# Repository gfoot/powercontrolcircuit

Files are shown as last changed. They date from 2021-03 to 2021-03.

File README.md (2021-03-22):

# Soft Power Switch Circuit with Tunable Overcurrent Protection Cutoff

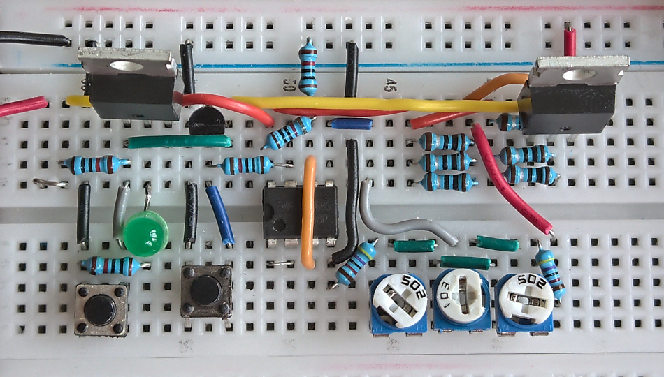
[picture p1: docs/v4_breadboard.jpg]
Power control circuit assembled on breadboard
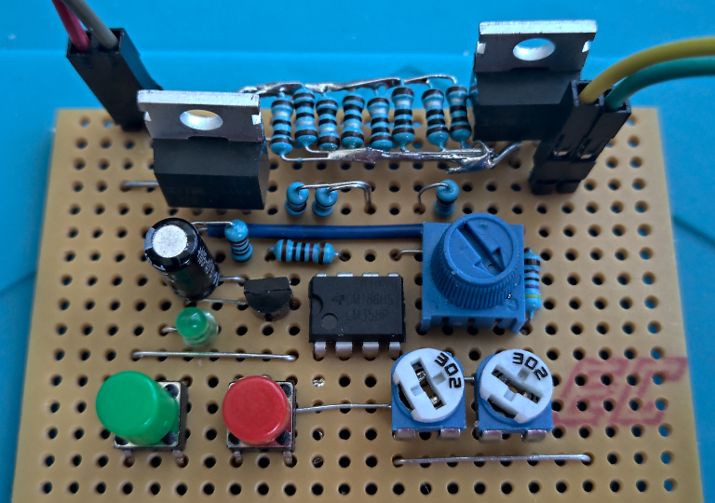
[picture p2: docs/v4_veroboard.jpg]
Power control circuit assembled on veroboard
 |  | <a href="http://www.youtube.com/watch?feature=player_embedded&v=DyxhS2SbpGM" target="_blank">Demo video on YouTube</a>
:----:|:----:|:----:
Assembled on breadboard | Assembled on veroboard | Demo video

This is a circuit for soft-switching a 5V DC input, with a configurable current limit cutoff, tested from around 10mA up to 1.2A.

This is useful because it protects your power supply, wiring, and components against adverse effects due to things like 
short circuiting, accidental reversed power polarity, placing components incorrectly or backwards in a circuit, or other
component failure.

It's not a boost/buck converter or regulator, just a switch for an existing regulated DC input.

## Operation

Press SW1 to turn the power on.  The LED indicates that power is on.  Press SW2 to turn the power off.

Use RV2 and RV3 to tune the range of currents that are selectable.  See [configuration guide](docs/configuration.md) for the tuning procedure.

Once tuned, RV1 selects the current limit.  When more than this amount of current is drawn, the circuit automatically powers off.

## Schematic

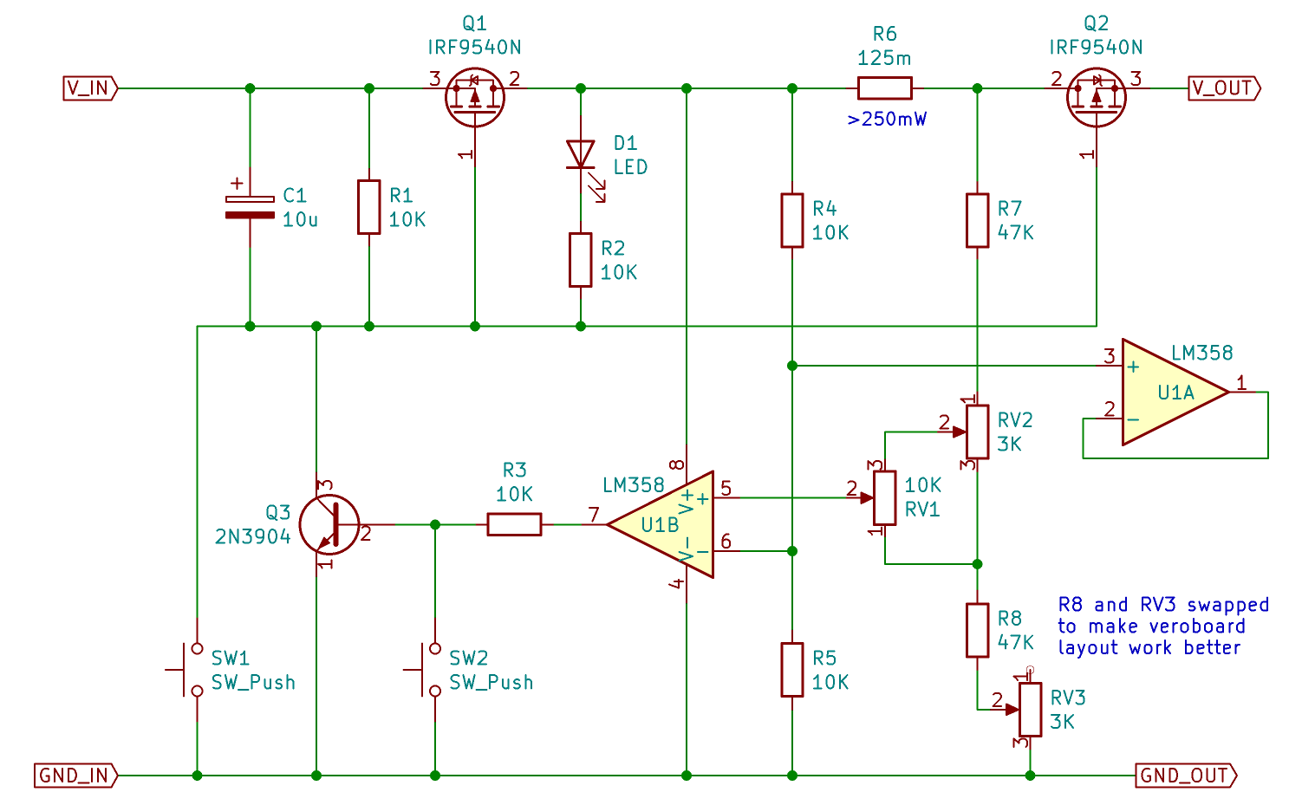
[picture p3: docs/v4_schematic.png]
Power control circuit schematic (v4)


## Bill of Materials

| Ref | Qty  | Spec | Notes |
| --- |:----:| ---- | ----- |
| Q1-2 | 2  | IRF9540N | P-channel power MOSFET - ideally low RDS(on) at VGS=-4.25V |
| Q3 | 1  | 2N3904 | NPN BJT transistor |
| R1-5 | 5  | 10K | Resistor |
| R6 | 1  | ~0.1 ohm | Power resistor, 1A continuous current, at least 1W recommended |
| R7-8 | 2  | 47K | Resistor |
| RV1-2  | 2  | 3K | Trim pots |
| RV3 | 1  | 10K | Potentiometer |
| U1 | 1  | LM385 | Operational amplifier |
| C1 | 1  | 10u | Capacitor to prevent accidental power-on (may not be necessary) |

Exact component choices are not critical.  With the above components, and 6x1ohm 250mW resistors in parallel for R6, at a continuous 1A load, 
the resistors get slightly warm to the touch and the MOSFET tabs measure 60C-70C, in open air with no heatsinks or active cooling.

The added output impedance appears to be approximately 0.75 ohms with these components, at a load current of 1A; lower currents 
lead to lower impedance.  Choosing Q1-2 with lower RDS(on) at -4.25V or more will have the greatest effect on impedance.

## Improvements

I'm considering the following:

* Use a charge pump to lower the gate voltage to Q1-2, to improve impedance at high loads
* Configure the op amp with feedback to amplify the voltage difference, in case it makes tuning the cutoff simpler
* Add an optional linear regulator to guarantee output voltage at high loads

Other suggestions very welcome!

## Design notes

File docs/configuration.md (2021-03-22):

# Configuring the current limiting feature

The circuit includes a series of resistors and potentiometers that form a
potential divider to determine the cutoff current.

Generally the range this needs to cover is approximately a division ratio
between about 50% and 55%.  Three potentiometers are used to configure this -
the idea is that RV2 and RV3 are "trim pots", used to fairly permanently set
some endpoints for the range that is then dynamically configured by the user
using RV1.

This document describes a method for calibrating these endpoints by tuning the
settings of RV2 and RV3.

To do this for large currents you really need a decent quality adjustable
electronic load, that can draw the required current for at least around 20s
without overheating - and preferably indefinitely.  I built a basic one from a
MOSFET and a bank of resistors which works well but requires a heatsink for
long term operation.  I'll discuss lower-tech alternatives below after going
through the general procedure.

# Tuning procedure

Before starting, you need a range of current limits in mind.

I've generally used 10mA and 1A as the target thresholds.  If you don't need
high currents, you may choose to reduce the upper limit to get more control at
the low end.

## Step 1 - Initial setup

* Set RV2 to a medium setting and RV3 to its maximum setting.
* Set RV1 to its minimum setting.
* Set your variable load to draw the low current amount, e.g. 10mA.
* Turn on the power; it should stay on.  If it doesn't, then increase RV2 until
it does stay on.

If it's not possible to get the power to stay on then you may need to adjust
some component values - using wider ranged pots for RV2 and RV3, or increasing
R7 and R8.

## Step 2 - Tune minimum current setting via RV3

* Set your variable load to draw the low current
* Set RV1 to minimum
* Turn on the circuit and check it stays on - if it doesn't, increase RV3 until it stays on
* Then decrease RV3 until it turns off

## Step 3 - Tune maximum current setting via RV2

* Set your variable load to draw the high current amount
* Set RV1 to maximum
* Turn on the circuit and check it stays on - if it doesn't, increase RV2 until it stays on
* Decrease RV2 until the circuit turns off

Repeat steps 2 and 3 until you're happy with the behaviour at the extreme
settings of RV1.  For me it only takes a couple of iterations to get settings
that work well.

You should then find that the rest of RV1's range maps fairly linearly to the
current values in-between.

# If you don't have a variable electronic load...

In case you don't have a proper electronic load that can draw a configurable
constant current, here are some other options.

For the low current calibration, you can just use normal resistors.  10mA over
5V requires 500 ohms and generates 50mW, which is fine for typical cheap
resistors - it'll get warm but not hot.  You can check the actual current flow
using an ammeter of course, and if you're concerned about the heat at 50mW, you
could use two 1K resistors in parallel instead.

For the high current calibration, normal resistors aren't really practical as
they can't deal with the amount of heat that gets generated - it's 5W for 1A
over 5V.  You'd need to spread that over about 100 resistors.  If you have a
suitable power resistor, with heat sink, then you could use that.

Personally I made my own electronic load to help test this circuit, which
worked quite well.  I think I'm currently using 9 x 47-ohm resistors in
parallel and an IRFZ34 MOSFET with heat sink, and a potentiometer to control
the gate voltage.  There are sure to be better designs available online.

It doesn't matter what the load is though so long as it draws this current, so
if you have any device that draws 1A at 5V, you could hook that up.  It doesn't
need to be a variable load.

You can also instead tune the "medium" setting of RV1 to match a lower current
limit - perhaps making it match the current draw of one of your own circuits.
Then turning RV1 up to maximum would allow for approximately doubling that
current flow before cutting off.

Finally, if you're not using a regulated load, check the actual current flow
using an ammeter in series, as unregulated loads will vary with temperature.

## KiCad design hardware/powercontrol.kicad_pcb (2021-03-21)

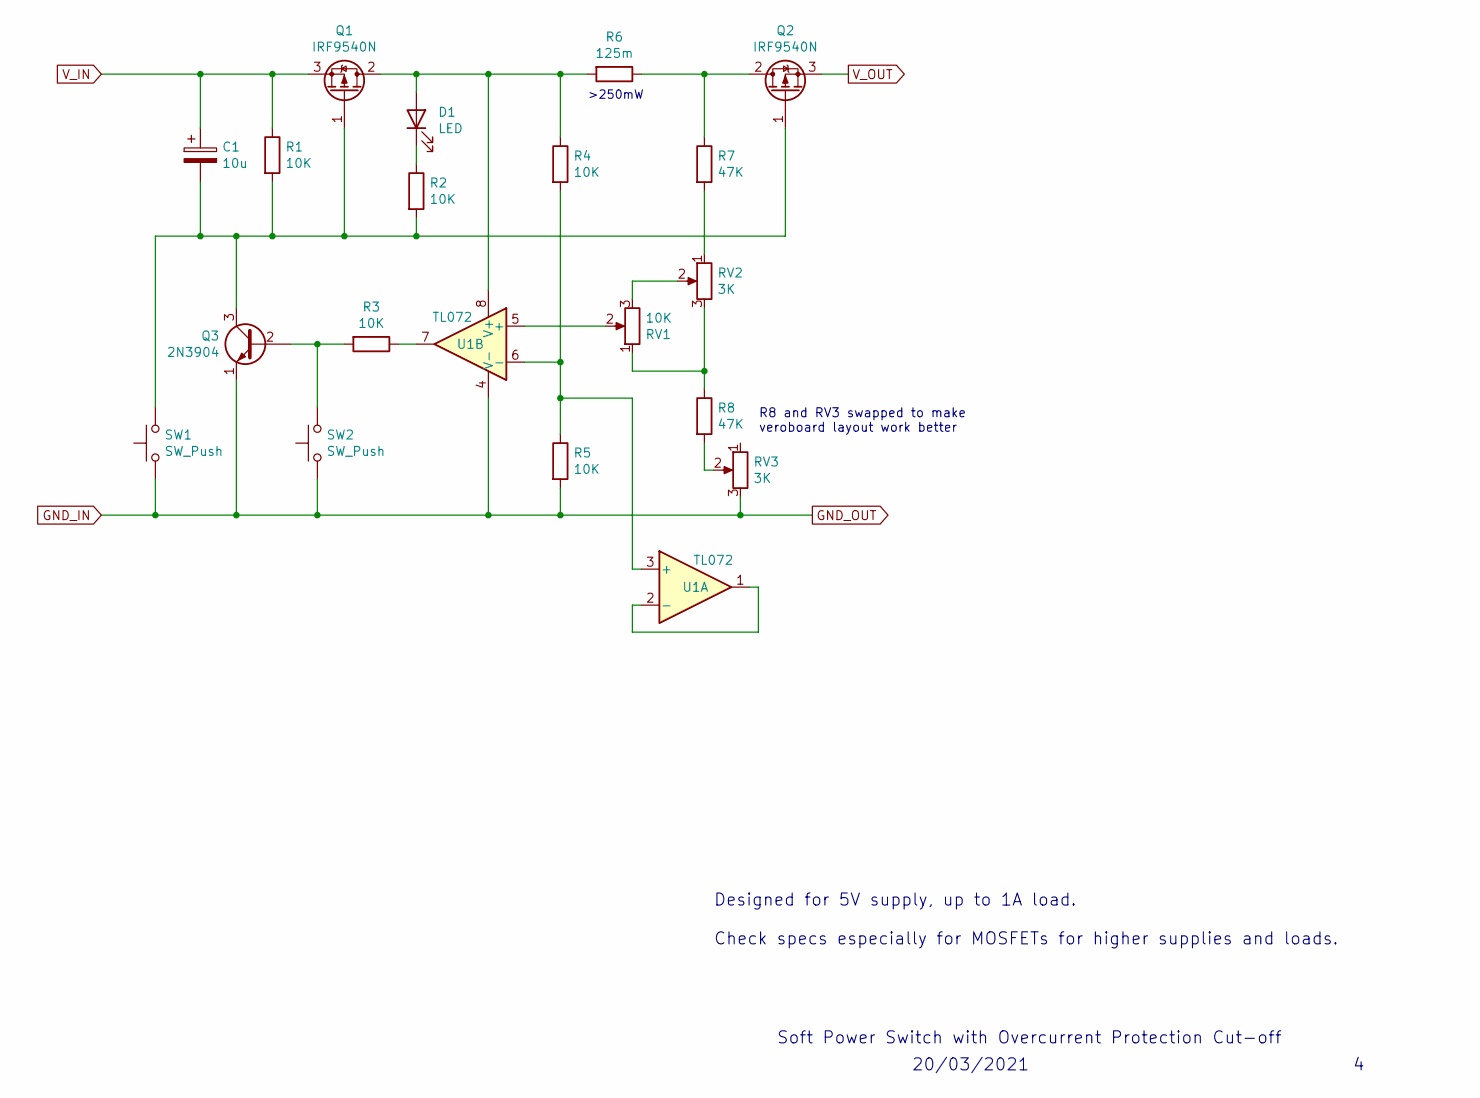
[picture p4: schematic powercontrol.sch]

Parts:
C1: 10u; CP_Radial_D5.0mm_P2.50mm
D1: LED; LED_D3.0mm
Q1, Q2: IRF9540N; TO-220-3_Vertical
Q3: 2N3904; TO-92_Inline_Wide
R1, R2, R3, R4, R5: 10K; R_Axial_DIN0204_L3.6mm_D1.6mm_P7.62mm_Horizontal
R6: 125m; R_Axial_Power_L20.0mm_W6.4mm_P25.40mm
R7, R8: 47K; R_Axial_DIN0204_L3.6mm_D1.6mm_P7.62mm_Horizontal
RV1: 10K; Potentiometer_Vishay_T73YP_Vertical
RV2, RV3: 3K; Potentiometer_Runtron_RM-065_Vertical
SW1, SW2: SW_Push; SW_PUSH_6mm_H5mm
U1: TL072; DIP-8_W7.62mm

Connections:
GND_IN: Q3.1 (E), R5.2, RV3.3, SW1.2, SW2.2, U1.4 (V-)
unnamed: C1.2, Q1.1 (G), Q2.1 (G), Q3.3 (C), R1.2, R2.2, SW1.1
unnamed: D1.1 (K), R2.1
unnamed: D1.2 (A), Q1.2 (D), R4.1, R6.2, U1.8 (V+)
unnamed: Q2.2 (D), R6.1, R7.1
unnamed: Q3.2 (B), R3.2, SW2.1
unnamed: R3.1, U1.7
unnamed: R4.2, R5.1, U1.3 (+), U1.6 (-)
unnamed: R7.2, RV2.1
unnamed: R8.1, RV1.1, RV2.3
unnamed: R8.2, RV3.2
unnamed: RV1.2, U1.5 (+)
unnamed: RV1.3, RV2.2
unnamed: U1.1, U1.2 (-)
V_IN: C1.1, Q1.3 (S), R1.1
V_OUT: Q2.3 (S)

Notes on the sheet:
Soft Power Switch with Overcurrent Protection Cut-off
20/03/2021
Designed for 5V supply, up to 1A load. Check specs especially for MOSFETs for higher supplies and loads.
>250mW
R8 and RV3 swapped to make veroboard layout work better

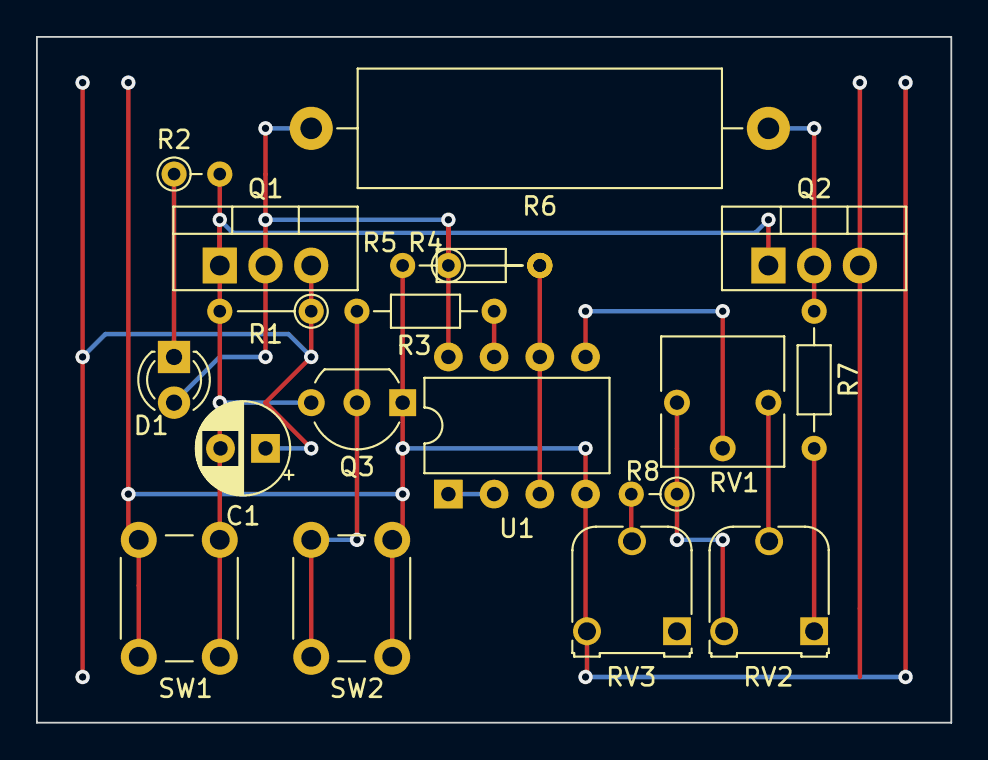
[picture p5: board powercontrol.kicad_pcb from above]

Board: 2 copper layers, 50.8 x 38.1 mm, 19 parts (0 on the bottom side), 15 nets.

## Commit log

2021-03-20 rev 2 schematic, veroboard layout
    [powercontrol.kicad_pcb, powercontrol.sch]
2021-03-21 V4 - Veroboard layout fixes, actually built and tested on veroboard now
    [powercontrol.kicad_pcb, powercontrol.sch]
2021-03-22 Add images of breadboard, veroboard, schematic
    [powercontrol.sch]
